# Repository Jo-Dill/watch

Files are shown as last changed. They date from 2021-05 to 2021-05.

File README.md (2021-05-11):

# watch
In this project I built a clock. The aim was to learn how to design and solder a PCB in order to keep the watch as small as possible and practical for everyday use. In this project, I also wanted to learn about low power electronics in order to give the clock as long a battery life as possible.

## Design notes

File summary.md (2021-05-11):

This watch has a few bugs. Nevertheless, I am not working on a second version. 
On the one hand, that would take a lot of time as well as I have way too many other ideas that I would like to realize. 
The power supply is the biggest problem so far. The circuit board is designed so that a Cr2032 coin cell supplies the clock with power.
Unfortunately, I didn't consider the early voltage drop to 2.7B and below.  2.8 V is the lowest voltage at which the LEDs still run reliably.
So I used a 3.7 V lipo whose voltage is regulated by the Xiao's internal voltage regulator (unfortunately an additional energy loss). 
The voltage measurement for the battery level display then had to be done via an external raster board. And now Everything is wired with enamelled copper wire. 
The LEDs are also not at all power-efficient (1.2 mA when they are all off - but in this case their power supply is cut by a transistor). 

What I have learned from this:
-The voltage source should be better adapted to components with a critical voltage range.
-Ws28 12b LEDs are NOT power saving.
-Coin Cells have a big capacity with their small package and a small drain. BUT their discharge curve isnt very horizontal

The Buzzer, driving the leds, the RTC, the light sensor and the power saving in standby worked well. 
After 2 months, mostly in standby, the battery is still more than a third of its capacity.
The operation via 2 buttons is possible, but can be improved in future projects, as it is not really intuitive due to multiple assignments.

In summary, I can say that I have learned a lot and will apply the knowledge in the next wearable project.
Maybe there will be a really smart watch with IOT functions or other wearable projects with low power requirements and small size.

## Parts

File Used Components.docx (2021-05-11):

Used Components

Amazon

MCU: Seeduino Xiao

LCSC

Buzzer: LCSC#: C255307

Button: LCSC#: C319375

Lightsensor: LCSC#: C84991

Batteryholder: LCSC#: C964833

Zener Diodes: LCSC#: C42267

Ebay/Amazon

different SMD Capacitors: size 0603

between the leds 100nf

different SMD Resistors: size 0603

- Search for Sample Book 0603

Ebay

Transistors: BC817-40 NPN 45V 0,5A SOT23

Leds: WS2812B 3535

Power delivery:

CR2032 first Idea

problem: the voltage drops early to 2.7 V and the lowest voltage for the whole system to work is 2.8 V. At this point the leds start to do weird stuff)

  - Solution: lipo

low current Lipo Size: 300926

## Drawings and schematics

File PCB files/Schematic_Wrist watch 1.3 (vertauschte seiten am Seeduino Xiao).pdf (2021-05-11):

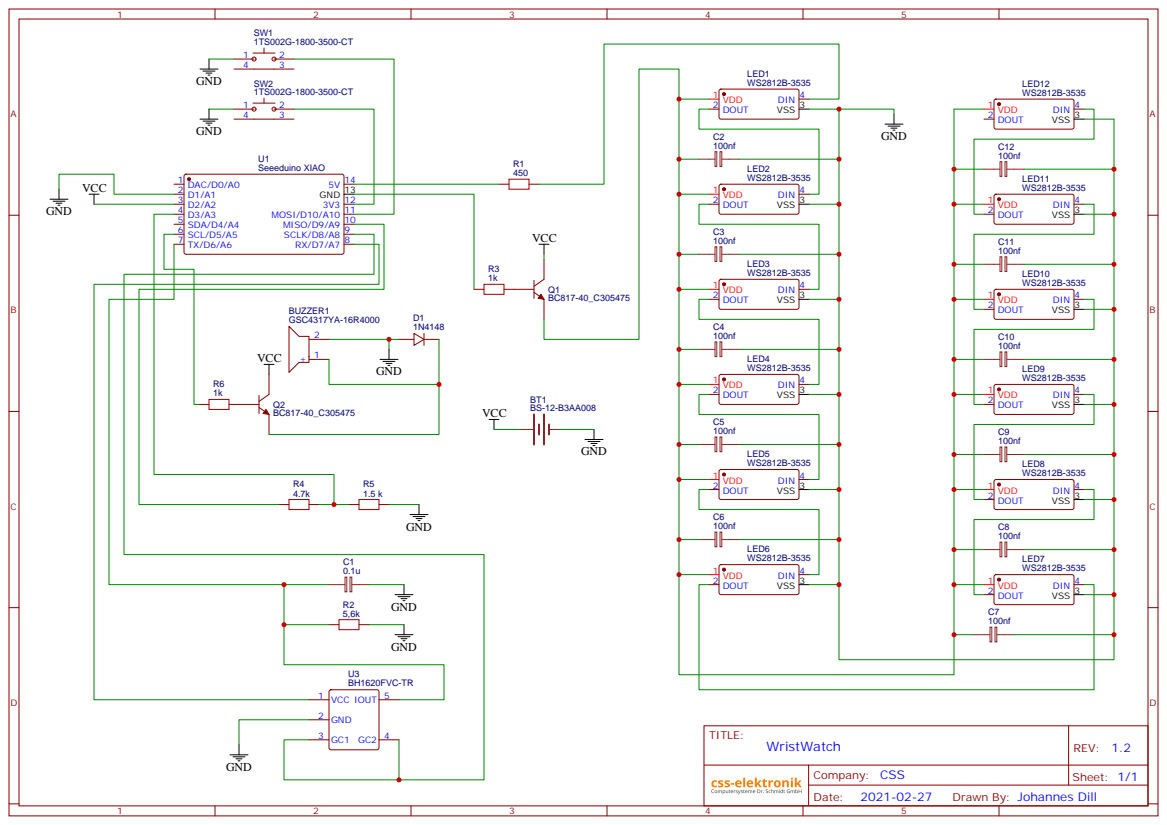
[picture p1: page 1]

Drawn By: Johannes Dill

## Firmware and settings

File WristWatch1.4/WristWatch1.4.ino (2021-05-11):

#include "ArduinoLowPower.h"
#include <Adafruit_NeoPixel.h>
#include <RTCZero.h>
//--------------------------------------------------------Pins in Proto
#define  upbuttonPin           2   //buttons
#define  downbuttonPin     3
#define  batteryreaderOutPin       10     //batteryvoltage
#define  batteryreaderInPin     4
#define  lightsensorVCCPin         6     //lightsensor
#define  lightsensorActivatePin     5
#define  lightsensorInPin     7
#define  ledactivatePin      1           //led
#define  leddataPin     0
#define  buzzerPin      8               //buzzer



RTCZero rtc;

byte startup = 0; //0: no startup yet , 1: startup was done
byte runningProg= 0; //says what the watch should do
byte brightness = 0; //regulates the brightness can be from 0 to 255
byte standbystate = 0;//if autostandby is on: 1 , off: 0
byte upButtonrelease = 0; //if 1 button was already recognized
byte downButtonrelease = 0; //if 1 button was already recognized
unsigned long upButtonrealeaseTimer = 0;
unsigned long downButtonrealeaseTimer = 0;
int standbyTime = 3000; //defines the time between last valid button press and auto standby
byte downButton= 0;  // 1 if button pressed
byte upButton = 0;
byte SoundState=0; //is a sound playing or not
byte timerStep=0;  //timerset variables (here because c__alram needs access too)
byte timerHours = 0;
byte timerMinutes = 0;


void  pinSetup();
void  interruptSetup();
void  neopixelSetup();
void  showSimpleTime();
void  showCompleteTime();
void  alarm();
void  alarmSet();
void  timerSet();
void  settings();
void  menue();
void  buttonHandler();
void  standbyloop ();
void  standbyreset();
void  showCompleteTimeReset();
void  resetmenue();
void  timerSet();
void  Flashlight();
void  SOS ();

void setup() {
  Serial.begin(9600);
  batteryLevelSetup();
  pinSetup();
  interruptSetup(); //after PinSetup
  neopixelSetup();
  RTCSetup ();
  Serial.println("setupdone");
}

void loop() {
  //Serial.print("Time is :"); Serial.print(rtc.getHours()); Serial.println(rtc.getMinutes());
 // Serial.print("runningProg");Serial.println(runningProg);
//Serial.print("brightness :"); Serial.println(brightness);
if (startup == 0){start();}else{

switch (runningProg){
  case 0:
    showSimpleTime();
   break;
  case 1:
    showCompleteTime();
   break;
  case 2: 
    alarm();
   break;
  case 3:
    menue();
  break;
  case 4:
    alarmSet();
  break;
  case 5:
    timerSet(); 
  break;
  case 6:
    settings();
  break;
  case 7:
    deleteAlarm(); 
  break;
  case 8:
    batteryLevel(); //noch nicht fertig
  break;
  case 9:
    Flashlight(); 
  break;
  case 10:
    SOS (); 
  break;
  case 11:
    TimeSet();
  break;
  case 12:
    Brightness();
  break;
  case 13:
    AutoBrightness();//noch nicht fertig
  break;
  case 14:
    test();
  break;
  default:
  runningProg= 0;
  break;

}

if(SoundState!=0){SoundPlayer();}
buttonHandler ();
standbyloop ();
}
}

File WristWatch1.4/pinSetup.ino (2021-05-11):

void pinSetup(){
   pinMode(upbuttonPin , INPUT_PULLUP);
   pinMode(downbuttonPin , INPUT_PULLUP);
   pinMode(batteryreaderOutPin , OUTPUT);
   pinMode(lightsensorVCCPin , OUTPUT);
   pinMode(lightsensorActivatePin , OUTPUT);
   pinMode(ledactivatePin , OUTPUT);         
   pinMode(buzzerPin , OUTPUT);
   Serial.println("pinSetup");
}

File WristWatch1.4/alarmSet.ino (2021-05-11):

byte alarmHours = 0;
byte alarmMinutes = 0;
byte alarmStep =0;
byte alarmRepetitions = 0;
byte alarmMinuteLed =0;
unsigned long alarmMinutesLedTime =0;

void alarmSet (){
  byte overlapping = 0;
  
  //Serial.print("alarmStep");Serial.print(alarmStep);Serial.print(" alarmHours");Serial.print(alarmHours);Serial.print(" alarmMinutes");Serial.println(alarmMinutes);
  switch (alarmStep){
    case 0://set hours
     if (digitalRead(downbuttonPin)== LOW && downButtonrelease ==0){
        downButtonrelease = 1;
        downButton = 1;
        }
   
      if (digitalRead(upbuttonPin)== LOW && upButtonrelease ==0){
         upButtonrelease = 1;
         upButton = 1;
        }
   
      if(upButton== 1 && downButton == 1 && upButtonrelease ==0 && downButtonrelease ==0){ //both pressed an released
           alarmStep=1; resetbuttons();
        }
    
      if(upButton== 1 && downButton == 0 && upButtonrelease ==0 && downButtonrelease ==0){ //just up pressed and released
           alarmHours++; resetbuttons();
        }

      if(upButton == 0 && downButton == 1 && upButtonrelease ==0 && downButtonrelease ==0){ //just down pressed and released
           alarmHours--; resetbuttons();
        }
            
      if(alarmHours > 12){alarmHours=alarmHours-12;}
      if(alarmHours <= 0){alarmHours =12;}
      pixels.clear();
      orientationLights();
      pixels.setPixelColor((alarmHours-1), pixels.Color(0,255,0));
      pixels.show();
     
    break;

    case 1: // set minutes in 5er Blocks
      //Serial.println(alarmMinutes);
      if (digitalRead(downbuttonPin)== LOW && downButtonrelease ==0){
        downButtonrelease = 1;
        downButton = 1;
      
        }
   
      if (digitalRead(upbuttonPin)== LOW && upButtonrelease ==0){
         upButtonrelease = 1;
         upButton = 1;
         
        }
   
      if(upButton== 1 && downButton == 1 && upButtonrelease ==0 && downButtonrelease ==0){ //both pressed an released
           alarmStep=2; resetbuttons();
        }
    
      if(upButton== 1 && downButton == 0 && upButtonrelease ==0 && downButtonrelease ==0){ //just up pressed and released
           alarmMinutes += 5; resetbuttons();
        }

      if(upButton == 0 && downButton == 1 && upButtonrelease ==0 && downButtonrelease ==0){ //just down pressed and released
           alarmMinutes -= 5; resetbuttons();
        }
      if(alarmMinutes>250){alarmMinutes=55;}
      if(alarmMinutes>55 && alarmMinutes<250){alarmMinutes=0;}

          
      pixels.clear();
      orientationLights();
      overlapping = 0;
      if(alarmMinutes<5){if (12!=alarmHours){
        pixels.setPixelColor((alarmHours-1), pixels.Color(0,255,0)); overlapping=0;}else{overlapping=255;} 
        pixels.setPixelColor(11, pixels.Color(255,overlapping,0));
        pixels.show();
      }else{
        if ((alarmMinutes/5) !=alarmHours){ pixels.setPixelColor((alarmHours-1), pixels.Color(0,255,0)); overlapping=0;}else{overlapping=255;}
         pixels.setPixelColor(((alarmMinutes/5)-1), pixels.Color(255,overlapping,0));
      
      pixels.show();
    }


    break;

    case 2:  //set minutes precise
      if (digitalRead(downbuttonPin)== LOW && downButtonrelease ==0){
        downButtonrelease = 1;
        downButton = 1;
        }
   
      if (digitalRead(upbuttonPin)== LOW && upButtonrelease ==0){
         upButtonrelease = 1;
         upButton = 1;
        }
   
      if(upButton== 1 && downButton == 1 && upButtonrelease ==0 && downButtonrelease ==0){ //both pressed an released
           alarmStep=3; resetbuttons();
        }
    
      if(upButton== 1 && downButton == 0 && upButtonrelease ==0 && downButtonrelease ==0){ //just up pressed and released
           alarmMinutes ++; resetbuttons();
        }

      if(upButton == 0 && downButton == 1 && upButtonrelease ==0 && downButtonrelease ==0){ //just down pressed and released
           alarmMinutes --; resetbuttons();
        }

      if(alarmMinutes>250){alarmMinutes=59;}
      if(alarmMinutes>59 && alarmMinutes<250){alarmMinutes=0;}

       pixels.clear();
       orientationLights();
       if(alarmMinutes<5){
          alarmMinuteLed=12; 
          if(alarmRepetitions==7){alarmRepetitions = alarmMinutes +1; alarmMinutesLedTime= millis(); }
       }else{
          alarmMinuteLed = alarmMinutes / 5;
          if(alarmRepetitions==7){alarmRepetitions = alarmMinutes -(alarmMinuteLed * 5 )+1; alarmMinutesLedTime= millis(); }
       }
       overlapping = 0;
        if (alarmMinuteLed != alarmHours){ pixels.setPixelColor((alarmHours-1), pixels.Color(0,255,0)); overlapping=0;}else{overlapping=255;}
        
        pixels.setPixelColor((alarmMinuteLed-1), pixels.Color(255,overlapping,0));
        if ((millis() -alarmMinutesLedTime)>200){pixels.setPixelColor((alarmMinuteLed-1), pixels.Color(0,overlapping,0));}
        if (((millis() -alarmMinutesLedTime)>400) && alarmRepetitions > 0){alarmMinutesLedTime= millis(); alarmRepetitions = alarmRepetitions-1;}
        if (alarmRepetitions <= 0){
            pixels.setPixelColor((alarmMinuteLed-1), pixels.Color(0,overlapping,0));
            //pixels.setPixelColor((alarmHours-1), pixels.Color(0,0,0));
            if((millis() -alarmMinutesLedTime)>1000){
              alarmRepetitions=7;  
            }
        }
        pixels.show();
      
    break;

    case 3: //save settings
        pixels.clear();
        pixels.show();
        playsound(1);
        byte hoursnow= rtc.getHours();
        byte minutesnow= rtc.getMinutes();
        if (alarmHours== 12){alarmHours= 0;}
        if (hoursnow > alarmHours){alarmHours +=12;}
        if (hoursnow == alarmHours && minutesnow > alarmMinutes){alarmHours +=12;}
        rtc.setAlarmTime(alarmHours, alarmMinutes, 0);
        rtc.enableAlarm(rtc.MATCH_HHMMSS);
        standbyTime = 400;
        standbystate = 1 ;
        alarmStep=4;
    break;
    
 
  }
}

void deleteAlarm(){
  rtc.disableAlarm();
  alarmReset();
  pixels.clear();
  pixels.show();
  runningProg=0;
  delay(100);
  tone(buzzerPin, 4000, 30);
  delay(150);
  tone(buzzerPin, 3000, 30);
}

void alarmReset(){
  alarmStep =0;
  alarmMinutes =0;
  alarmHours = 0;
  alarmRepetitions = 0;
  alarmMinutesLedTime =0;
  alarmMinuteLed =0;
}

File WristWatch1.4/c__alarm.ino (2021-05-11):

    unsigned long lastLedChangeTime =0 ;
    byte alarmLed = 0;

  byte melodystep = 0;
  unsigned long lastmelodyChangeTime =0 ;
void alarm (){
  standbyTime = 180000;  
  pixels.setBrightness(200);
  const int ledChangetime = 100;
  if (millis()-lastLedChangeTime >= ledChangetime){
    lastLedChangeTime = millis();
    if (alarmLed < (NUMPIXELS-1)){alarmLed ++;}
    else{alarmLed=0;}
    pixels.clear();
    pixels.setPixelColor(alarmLed, pixels.Color(255, 0, 0));
    pixels.show();
  }

  const byte melody1_lenghth = 8;
  //const int melody1_frequency []={0,4000,0,4000,0,4000,0,4000};
  const int melody1_frequency []={0,3000,0,3000,0,4000,0,5000};
  const int melody1_duration []={2000,100,50,100,50,100,50,100};
  if (millis()- lastmelodyChangeTime > melody1_duration[melodystep]){
    lastmelodyChangeTime= millis();
    if(melodystep< melody1_lenghth){melodystep++;}else{melodystep=0;}
    tone(buzzerPin, melody1_frequency [melodystep], melody1_duration [melodystep]);
    if(melody1_frequency [melodystep]==0){noTone(buzzerPin);digitalWrite(buzzerPin, LOW);}
  } 
  //if (digitalRead(upbuttonPin)== LOW && upButtonrelease ==0){runningProg=0; upButtonrelease =1; AutoBrightness(); standbyTime = 2000;}
  //if (digitalRead(downbuttonPin)== LOW && downButtonrelease ==0){runningProg=0; downButtonrelease =1; AutoBrightness(); standbyTime = 2000;}
  
    if (digitalRead(downbuttonPin)== LOW && downButtonrelease ==0){
        downButtonrelease = 1;
        downButton = 1;
        }
   
    if (digitalRead(upbuttonPin)== LOW && upButtonrelease ==0){
         upButtonrelease = 1;
         upButton = 1;
        }
   
    if(upButton== 1 && downButton == 1 && upButtonrelease ==0 && downButtonrelease ==0){ //both pressed an released
          runningProg=0; AutoBrightness(); noTone(buzzerPin); deleteAlarm(); standbyTime = 2000; resetbuttons();
        }
    
    if(upButton== 1 && downButton == 0 && upButtonrelease ==0 && downButtonrelease ==0){ //just up pressed and released
           timerSetReset();
           timerStep=3;
           timerMinutes = 5;
           runningProg=5;
           resetbuttons();
        }

    if(upButton == 0 && downButton == 1 && upButtonrelease ==0 && downButtonrelease ==0){ //just down pressed and released
           timerSetReset();
           timerStep=3;
           timerMinutes = 1;
           runningProg=5;
           resetbuttons();
        }
            
}
